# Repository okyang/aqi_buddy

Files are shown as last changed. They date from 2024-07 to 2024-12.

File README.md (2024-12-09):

<!-- TOC start (generated with https://github.com/derlin/bitdowntoc) -->

- [AQI Buddy](#aqi-buddy)
- [Background](#background)
- [Pre-requisites](#pre-requisites)
- [Materials Needed](#materials-needed)
- [Tools Needed](#tools-needed)
- [Build Guide](#build-guide)
  - [1 - 3D Print the Case](#1---3d-print-the-case)
  - [2 - Building the Circuit!](#2---building-the-circuit)
  - [3 - Upload Code to Wio Terminal](#3---upload-code-to-wio-terminal)
  - [4 - Final Assembly](#4---final-assembly)
- [Things I Learned and Improvement Considerations](#things-i-learned-and-improvement-considerations)
- [References](#references)

<!-- TOC end -->

<!-- TOC -->

# AQI Buddy
AQI Buddy is a minimal air quality display using a Wio Terminal and Plantower PMS503. It is designed to be portable so you can measure the air quality anywhere you go. For example, the air quality when cooking, driving on the highway, outdoors, indoors, etc.

[Youtube Video](https://www.youtube.com/watch?v=UiudOHBMkqQ) | [Instructables](https://www.instructables.com/AQI-Buddy/) | [Hackster.io](https://www.hackster.io/owenyang123/aqi-buddy-57f7f1)

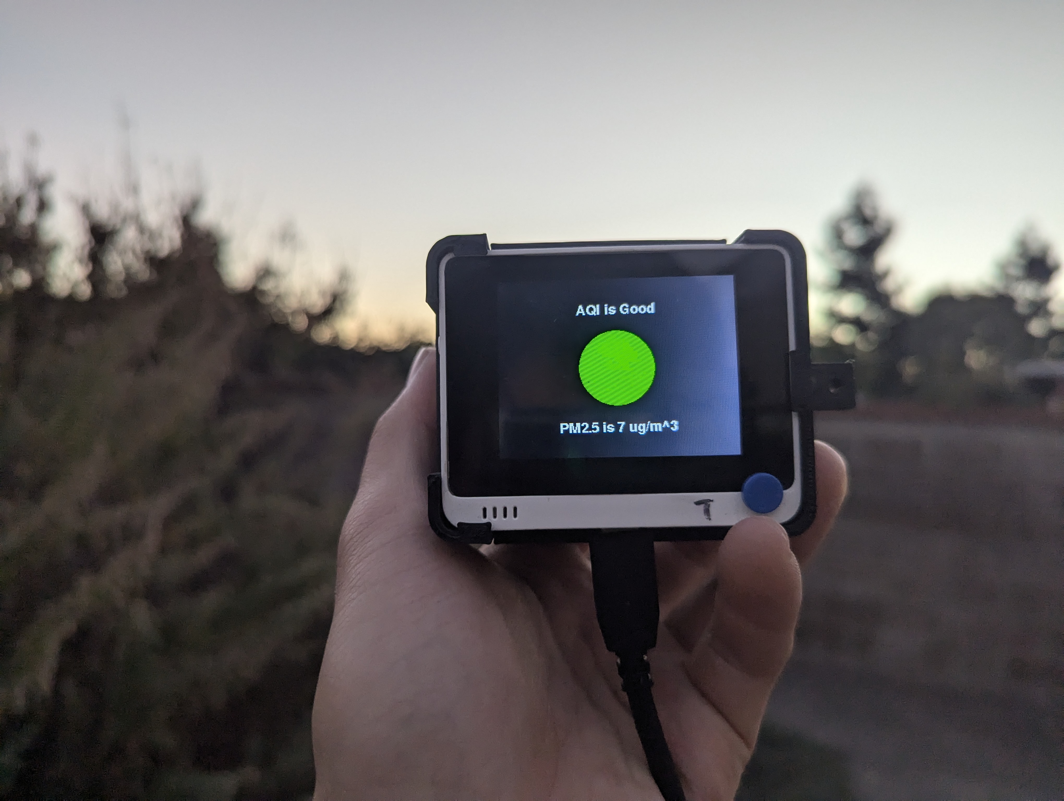
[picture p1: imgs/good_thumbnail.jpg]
thumbnail photo


# Background
Air Quality Index (AQI) meausre PM2.5 to help determine the air quality and impacts to human health. According to [World Air Quality Index Project](https://aqicn.org/calculator/), the US EPA standard for AQI is:

| AQI | Air Pollution Level | PM 2.5 |
| --- | --- | --- |
| 0 - 50 | Good | 0 - 12 |
| 51 - 100  | Moderate | 13 - 35 |
| 101 - 150 | Unhealthy for Sensitive Groups | 36 - 56 |
| 151 - 200 | Unhealthy | 57 - 150  |
| 201 - 300 | Very Unhealthy | 151 - 199 |
| 300+ | Hazordous | 200 + |

# Pre-requisites
- [ ] Soldering Skills
- [ ] Git
- [ ] [PlatformIO](https://platformio.org/)
- [ ] [Visual Studio Code](https://code.visualstudio.com/)

# Materials Needed
- [ ] [Wio Terminal](https://www.seeedstudio.com/Wio-Terminal-p-4509.html)
- [ ] [PM2.5 Air Quality Sensor and Breadboard Adapter Kit](https://www.adafruit.com/product/3686)
- [ ] PLA Filament for 3D Printer
- [ ] [M3 8MM Hex Screws](https://www.amazon.com/dp/B07CMQ1SQH)
- [ ] [M3x4x5mm Threaded Inserts](https://www.amazon.com/dp/B0CNVXWQYZ)
- [ ] M3 Nut
- [ ] Solder
- [ ] Male Header Pins
- [ ] Solid Electrical Wire
- [ ] USB-C Cable
- [ ] (Optional for Mobility) USB Power Bank

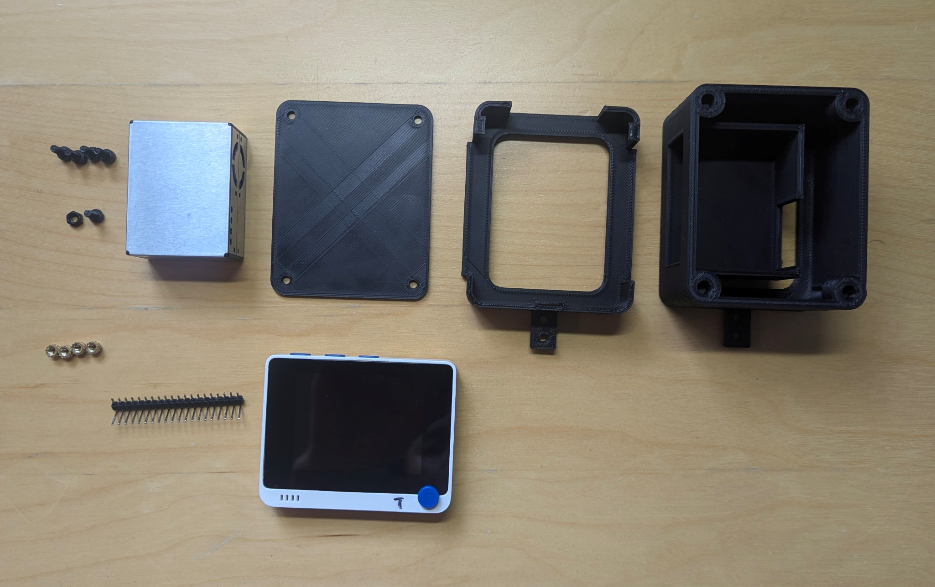
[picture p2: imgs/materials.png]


# Tools Needed
- [ ] 3D Printer
- [ ] Hex Key
- [ ] Soldering Iron

# Build Guide
Follow all these steps below to setup your on AQI Buddy 😁.

## 1 - 3D Print the Case
1. Print the following components
 2. [aqi_buddy_body.stl](./stl/aqi_buddy_body.stl) - this takes the longest
 3. [aqi_buddy_lid.stl](./stl/aqi_buddy_lid.stl)
 4. [aqi_buddy_wio.stl](./stl/aqi_buddy_wio.stl)
2. Add the 4 threaded inserts to the holes in **aqi_buddy_body.stl** with a soldering iron

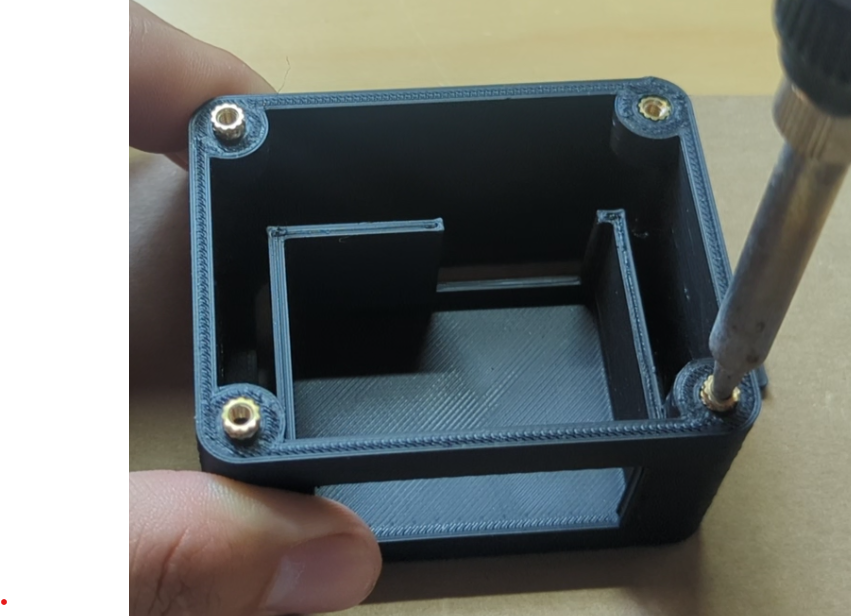
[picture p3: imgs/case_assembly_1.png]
Adding threaded inserts to case


I'm personally not great at CAD, so I am sharing this Onshape link if you want to improve the design yourself 😅: [okyang_aqi_buddy][onshape link]

## 2 - Building the Circuit!
Solder the male header pins to the aqi sensor breakout board using the circuit diagram below:
circuit diagram

1. Plug in the male headers to the left side of wio terminal socket
2. Solder your wires to the AQI sensor breakout board

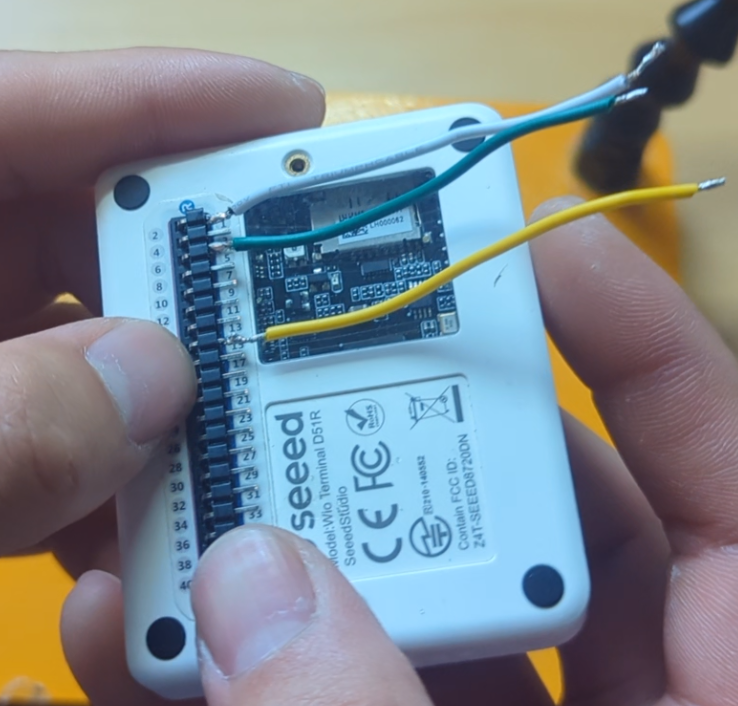
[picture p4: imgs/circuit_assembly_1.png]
adding header to wio terminal


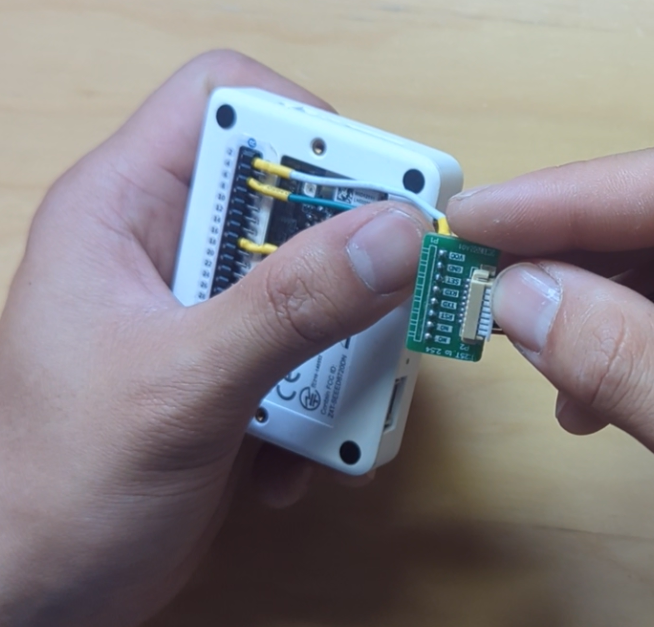
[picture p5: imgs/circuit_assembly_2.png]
soldered wires to aqi sensor breakout board


## 3 - Upload Code to Wio Terminal
1. Clone this repo
    ```shell
    git clone git@github.com:okyang/aqi_buddy.git
    ```
2. Pull necessary submodules
    ```shell
    git submodule update --init --recursive
    ```
3. Plug in your wio terminal
4. Upload the code

## 4 - Final Assembly
1. Place Wio Terminal in the Top side of the **aqi_buddy_wio** and feed the connection to the AQI sensor breakout board through the rectangular opening
2. Add in the **aqi_buddy_body** and align with the rectangular tab on the **aqi_buddy_wio**
3. Secure the **aqi_buddy_wio** by threading through a M3 screw to the closer hole and secure with a M3 nut
4. Slide in the AQI sensor to the **aqi_buddy_body** with the fan facing towards the opening (very important!)
5. Connect the cable from the AQI sensor breakout board to the AQI sensor
6. Finally, add the **aqi_sensor_lid** and screw in the four M3 screws

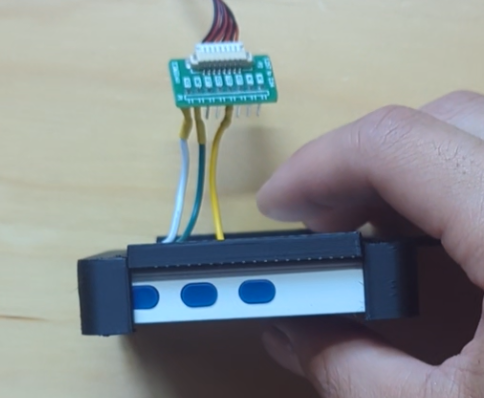
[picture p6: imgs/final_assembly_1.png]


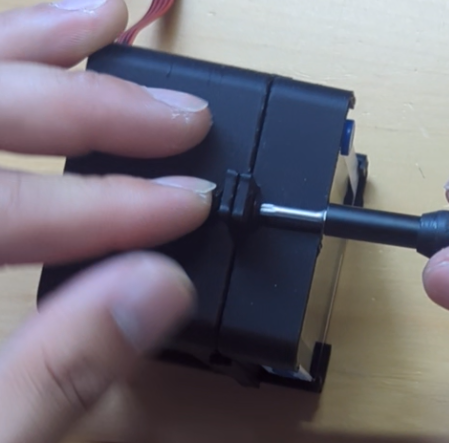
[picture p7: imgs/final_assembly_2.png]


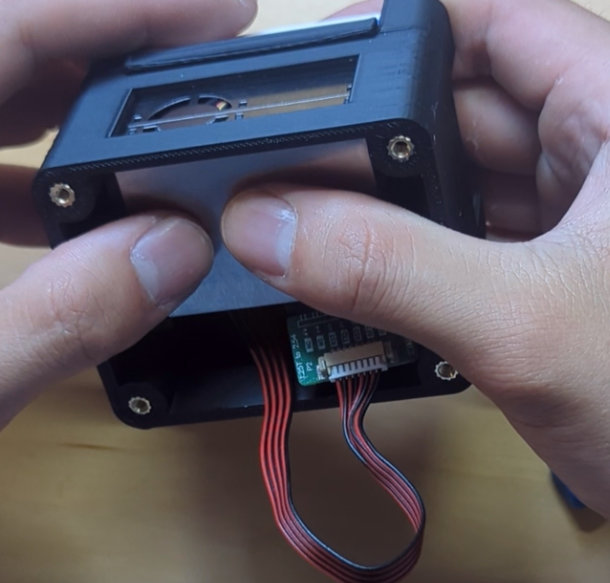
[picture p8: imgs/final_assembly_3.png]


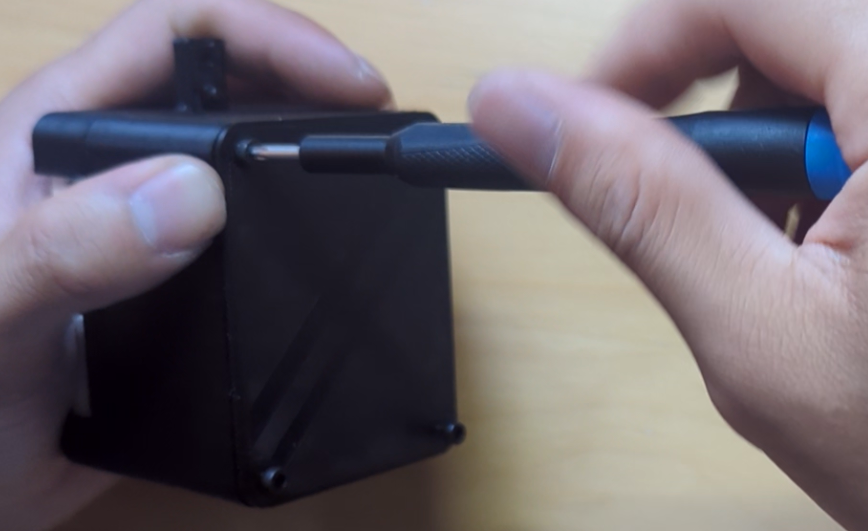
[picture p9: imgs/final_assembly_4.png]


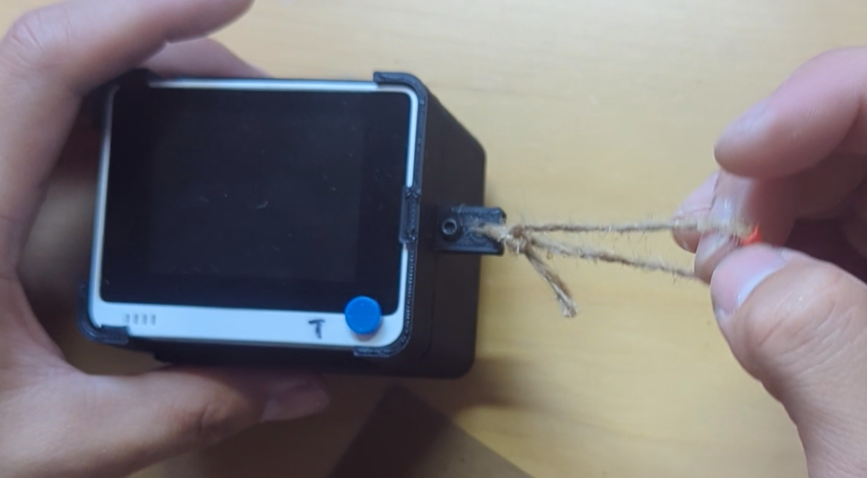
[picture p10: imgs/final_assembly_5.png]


# Things I Learned and Improvement Considerations
I am still a novice at CAD design, but I feel like there was so many little things I learned like how to use [variables](https://cad.onshape.com/help/Content/variable.htm) for my sketches, getting more familiar with the various tools in [Onshape](https://www.onshape.com/en/), and learning how to assemble parts together. This is probably very trivial to others, but not for me 😅.

I already knew some of this before, but setting up a Github Actions Workflow was very cool to see. I added a basic check that basically just compiles to code after each commit. This is definitely a very handy feature and very simple check make sure I didn't break the code for others.

Also, using [git submodules](https://git-scm.com/book/en/v2/Git-Tools-Submodules) was not a new concept to me, but definitely not something I used often. I used it in this project because of the dependencies on `Adafruit_BusIO` and  `Adafruit_PM25AQI`. I just thought this was a handy feature of git that other novice developers should know about as well.

The basic scope of the project seemed very simple, but I still feel like there is a lot of cool features that can be added. So for now to avoid [scope creep](https://www.forbes.com/advisor/business/scope-creep/), I will just write them down:
- Upload AQI Data to Influx Data or some IoT Dashboard
- Add a GPS, to collect location data (for a more mobile aqi sensor)
- Solar Powered + Weatherproof to mount the sensor outdoors
- Improve UI with [LVGL](https://lvgl.io/)
- Add an emotional character for each AQI level

# References
- [Wio Terminal Getting Started](https://wiki.seeedstudio.com/Wio-Terminal-Getting-Started/) - documentation for the Seeed studio wio terminal
- [Adafruit PM2.5 Sensor Quality Overview](https://learn.adafruit.com/pm25-air-quality-sensor/overview)
- [Adafruit PM25AQI Library](https://github.com/adafruit/Adafruit_PM25AQI)
- [PLANTOWER Datasheet](https://cdn-shop.adafruit.com/product-files/3686/plantower-pms5003-manual_v2-3.pdf)
- [Onshape CAD Design][onshape link] - CAD design for if you want to make any modifications to the case design

[onshape link]: https://cad.onshape.com/documents/0d690de565054810b2f57071/w/88b510ec140bf21b366c8841/e/53b255aacbf68a856bd73344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

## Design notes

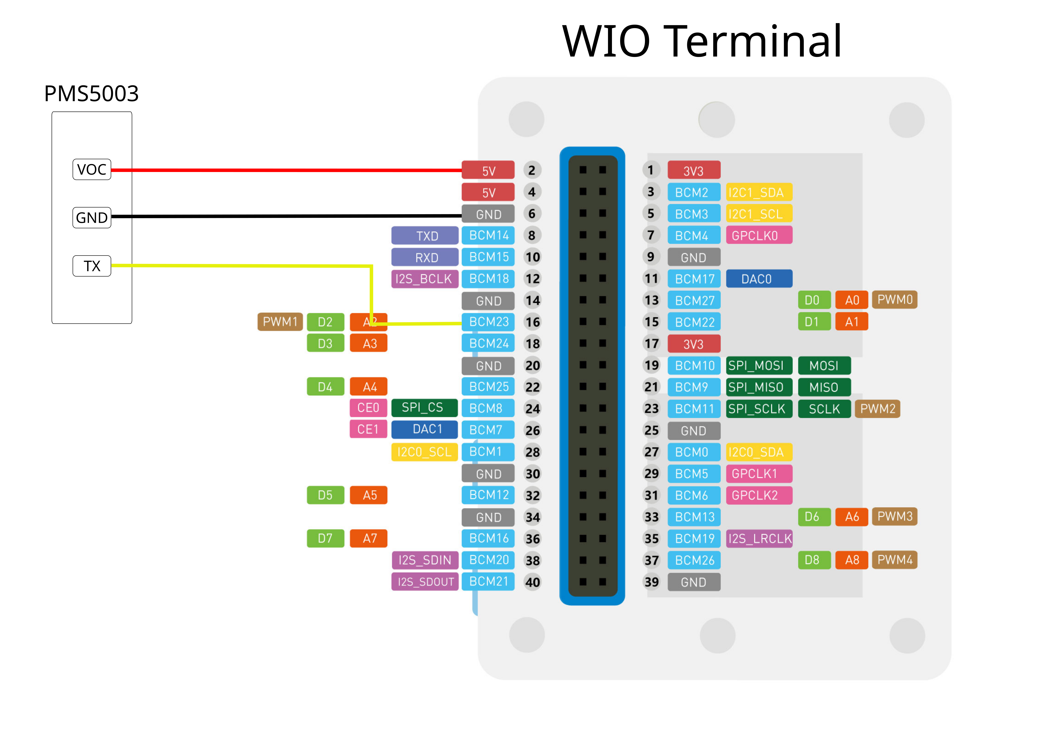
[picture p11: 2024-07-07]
imgs/circuit_diagram.png

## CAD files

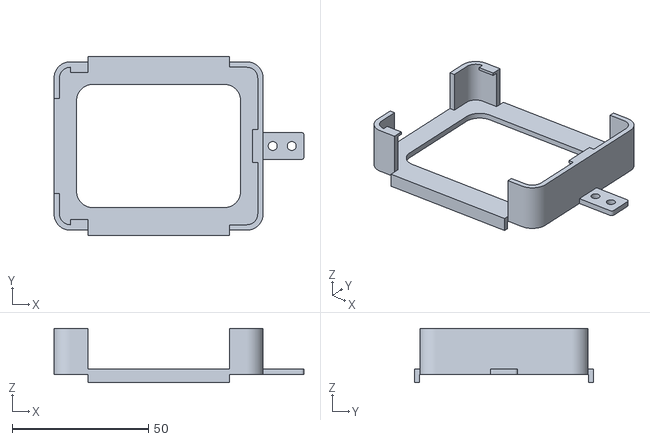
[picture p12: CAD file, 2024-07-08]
stl/aqi_buddy_wio.stl
91.9 x 65.9 x 19.9

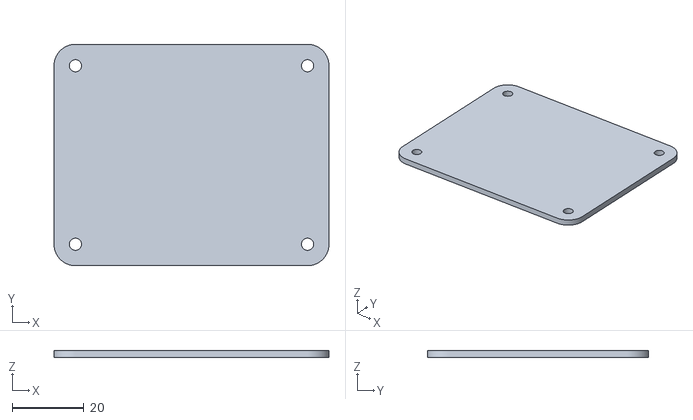
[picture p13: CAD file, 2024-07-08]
stl/aqi_buddy_lid.stl
76.9 x 61.9 x 2.00

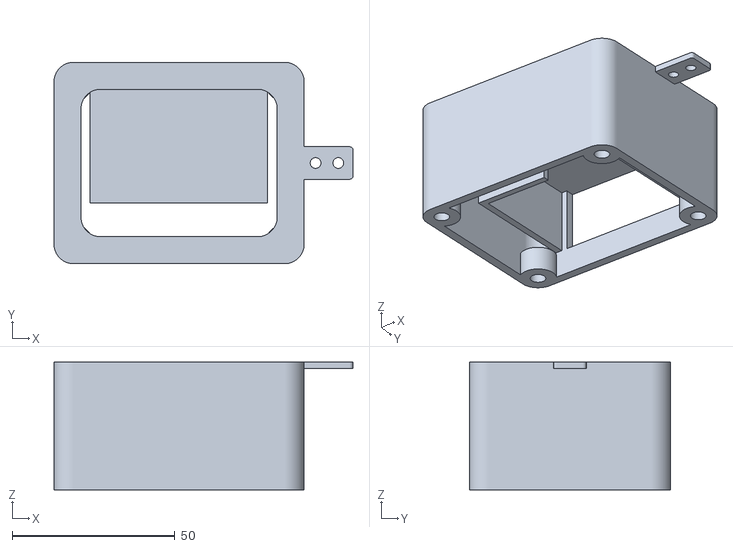
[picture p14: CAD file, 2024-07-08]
stl/aqi_buddy_body.stl
91.9 x 61.9 x 39.3

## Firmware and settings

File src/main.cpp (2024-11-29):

#include <Arduino.h>
#include <Adafruit_PM25AQI.h>
#include <SoftwareSerial.h>
#include "TFT_eSPI.h"
#include "Free_Fonts.h"

#define SCREEN_HEIGHT 240
#define SCREEN_WIDTH 320
#define TITLE_Y_POSITION 240 * 1 / 7   // title text position of pollution level
#define READING_Y_POSITION 240 * 4 / 5 // title text position of pm2.5 sensor

TFT_eSPI tft;
SoftwareSerial pmSerial(2, 3); // pin #2 is IN from sensor (TX pin on sensor), leave pin #3 disconnected
Adafruit_PM25AQI aqi = Adafruit_PM25AQI();
String previousPollutionLevelText = "";

/// @brief Setups screen orientation and tft font
void setupGraphics()
{
  tft.begin();
  tft.setRotation(3);
  tft.setFreeFont(FSSB9); //  Freefont, Sans Serif, Bold, 12pt
  tft.fillScreen(TFT_BLACK);
}

/// @brief Updates the graphics to reflect pm 2.5 readings. AQI level
/// is derived from https://aqicn.org/calculator/.
/// @param pm2p5 Represents the pm 2.5 readings from the sensor. units are ug/m^3
void updateGraphics(int pm2p5)
{
  // air quality color indicator
  String pollutionLevelText;
  int color = TFT_WHITE;
  if (pm2p5 < 0)
  {
    pollutionLevelText = "No AQI Data";
  }
  else if (0 <= pm2p5 && pm2p5 <= 12)
  {
    pollutionLevelText = "AQI is Good";
    color = TFT_GREEN;
  }
  else if (12 < pm2p5 && pm2p5 <= 35)
  {
    pollutionLevelText = "AQI is Moderate";
    color = TFT_GREENYELLOW;
  }
  else if (35 < pm2p5 && pm2p5 <= 56)
  {
    pollutionLevelText = "AQI is Unhealthy for Sensitive";
    color = TFT_YELLOW;
  }
  else
  {
    pollutionLevelText = "AQI is Unhealthy";
    color = TFT_RED;
  }

  // clear text in UI
  if (previousPollutionLevelText != pollutionLevelText)
  {
    tft.fillRect(0, TITLE_Y_POSITION, SCREEN_WIDTH, TITLE_Y_POSITION + 3, TFT_BLACK);
  }
  tft.fillRect(0, READING_Y_POSITION, SCREEN_WIDTH, READING_Y_POSITION + 3, TFT_BLACK);
  previousPollutionLevelText = pollutionLevelText;

  // draw in UI elements
  int pollutionLevelTextWidth = tft.textWidth(pollutionLevelText);
  tft.drawString(pollutionLevelText, (SCREEN_WIDTH - pollutionLevelTextWidth) / 2, TITLE_Y_POSITION);
  tft.fillCircle(SCREEN_WIDTH / 2, SCREEN_HEIGHT / 2, 50, color);

  // draw aqi level
  String aqiLevelText = "PM2.5 is " + String(pm2p5) + " ug/m^3";
  int aqiLevelTextWidth = tft.textWidth(aqiLevelText);
  tft.drawString(aqiLevelText, (SCREEN_WIDTH - aqiLevelTextWidth) / 2, READING_Y_POSITION);
  // tft.drawString("", (SCREEN_WIDTH - aqiLevelTextWidth) / 2, READING_Y_POSITION);
}

void setup()
{
  setupGraphics();
  updateGraphics(-1);

  // -------- Adafruit PMSA003I Air Quality Sensor Setup ----------
  // Wait for serial monitor to open
  Serial.begin(115200);

  Serial.println("Adafruit PMSA003I Air Quality Sensor");

  // Wait one second for sensor to boot up!
  delay(1000);

  // baud rate of the PM2.5 sensor is set
  pmSerial.begin(9600);

  if (!aqi.begin_UART(&pmSerial))
  { // connect to the sensor over software serial
    Serial.println("Could not find PM 2.5 sensor!");
    while (1)
      delay(10);
  }

  Serial.println("PM25 found!");
}

void loop()
{
  PM25_AQI_Data data;

  if (!aqi.read(&data))
  {
    delay(500); // try again in a bit!
    return;
  }

  Serial.println();
  Serial.println(F("---------------------------------------"));
  Serial.println(F("Concentration Units (standard)"));
  Serial.println(F("---------------------------------------"));
  Serial.print(F("PM 2.5: "));
  Serial.print(data.pm25_standard);
  Serial.println();

  // Update pm 2.5 graphics
  updateGraphics(data.pm25_standard);
  delay(100);
}

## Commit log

2024-05-28 add SPI dependency
2024-05-28 update readme with circuit diagram and more references
2024-06-20 Add UI for sensor reading
2024-07-07 update wiring diagram
2024-07-08 add build instructions to README
    [aqi_buddy_body.stl, aqi_buddy_lid.stl, aqi_buddy_wio.stl]
2024-07-15 add images to readme and restructure files
    [aqi_buddy_body.stl, aqi_buddy_lid.stl, aqi_buddy_wio.stl]
2024-11-29 fix output for serial monitor
    [main.cpp]
2024-12-08 add pm2.5 to materials list
